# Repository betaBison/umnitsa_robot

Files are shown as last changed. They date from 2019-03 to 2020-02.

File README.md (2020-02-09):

# umnitsa_robot
Umnitsa comes from the englsih transliteration of the russian word "умница" clever pesron or smarty-pants.
Umnitsa is designed to be a clever robot.  
  
See also [umnitsa_msgs](https://github.com/betaBison/umnitsa_msgs), [umnitsa_gs](https://github.com/betaBison/umnitsa_gs), amd [umnitsa_mechanical](https://github.com/betaBison/umnitsa_mechanical).
  
umnitsa_robot is a [metapackage](http://wiki.ros.org/catkin/package.xml#Metapackages) for all the packages that run on the robot's computer. Packages are located in the `src/` directory and a brief description of each is included below.

## Setup
This package is currently compatible with the Raspberry Pi 3 B+ and Jetson Nano.
   
### Raspberry Pi
Install needed dependencies:  
`pip install`

### Jetson Nano
Install needed dependencies:  
`pip2 install Jetson.GPIO pygame nanpy`

Since this repo contains the realsesnse-ros repository as a submodule it's important to run the following command  
`git clone --recursive <URL to git repo>`  
If you failed to do this initially, then inside this repository run  
`git submodule update --init --recursive`  
The realsense-ros also requires the latest [Intel RealSense SDK](https://github.com/IntelRealSense/librealsense/releases). Jetson Nano [installation instructions](https://github.com/JetsonHacksNano/installLibrealsense).

#### Arduino Firmware
Follow directions here to upload correct firmware to arduino (https://github.com/nanpy/nanpy-firmware)

#### Pygame errors:
If there are erros installing pygame, you may need to add its dependencies.  
`sudo apt install libsdl1.2-dev python-dev libsdl-image1.2-dev libsdl-mixer1.2-dev libsdl-ttf2.0-dev libsdl1.2-dev libsmpeg-dev python-numpy subversion libportmidi-dev ffmpeg libswscale-dev libavformat-dev libavcodec-dev`

### Desktop
Since this repo contains the realsesnse-ros repository as a submodule it's important to run the following command  
`git clone --recursive <URL to git repo>`  
If you failed to do this initially, then inside this repository run  
`git submodule update --init --recursive`  
The realsense-ros also requires the latest [Intel RealSense SDK](https://github.com/IntelRealSense/librealsense/releases). Linux [installation instructions](https://github.com/IntelRealSense/librealsense/blob/master/doc/distribution_linux.md). You must install the dev package  
`sudo apt install librealsense2-dkms librealsense2-utils librealsense2-dev`   
   
Install pygame for the joystick controller  
`pip2 install pygame`

## Package Overview
### umnitsa_robot
Empty package that declares packages inside the [metapackage](http://wiki.ros.org/catkin/package.xml#Metapackages).

### umnitsa_robot_launch
This package contains parameters adn launch files for the umnitsa robot. Parameters should be adjusted for compatibility with system setup.

### umnitsa_hardware
This package consists of the harware interfacing nodes as follows:
#### motors
outputs to the motor control board to control four DC motors  

Normal mode:  
The max throttle going forward is 71% on all motors, not 100%. This is so that moving the joystick in a steady
circle produces a steady cirlce of robot movement.  

Turbo mode:  
If the joystick is moved at all, one of the motors is set to 100% throttle. This makes it faster, but unfit for precise movement.

#### RGB
Outputs to the UmnitsaRGB custom PCB  

#### ultrasonic
Inputs from the UmnitsaUltra custom PCB

### umnitsa_joystick
Package that contains the node that that receives input from a switch pro controller and outputs to the joystick message.

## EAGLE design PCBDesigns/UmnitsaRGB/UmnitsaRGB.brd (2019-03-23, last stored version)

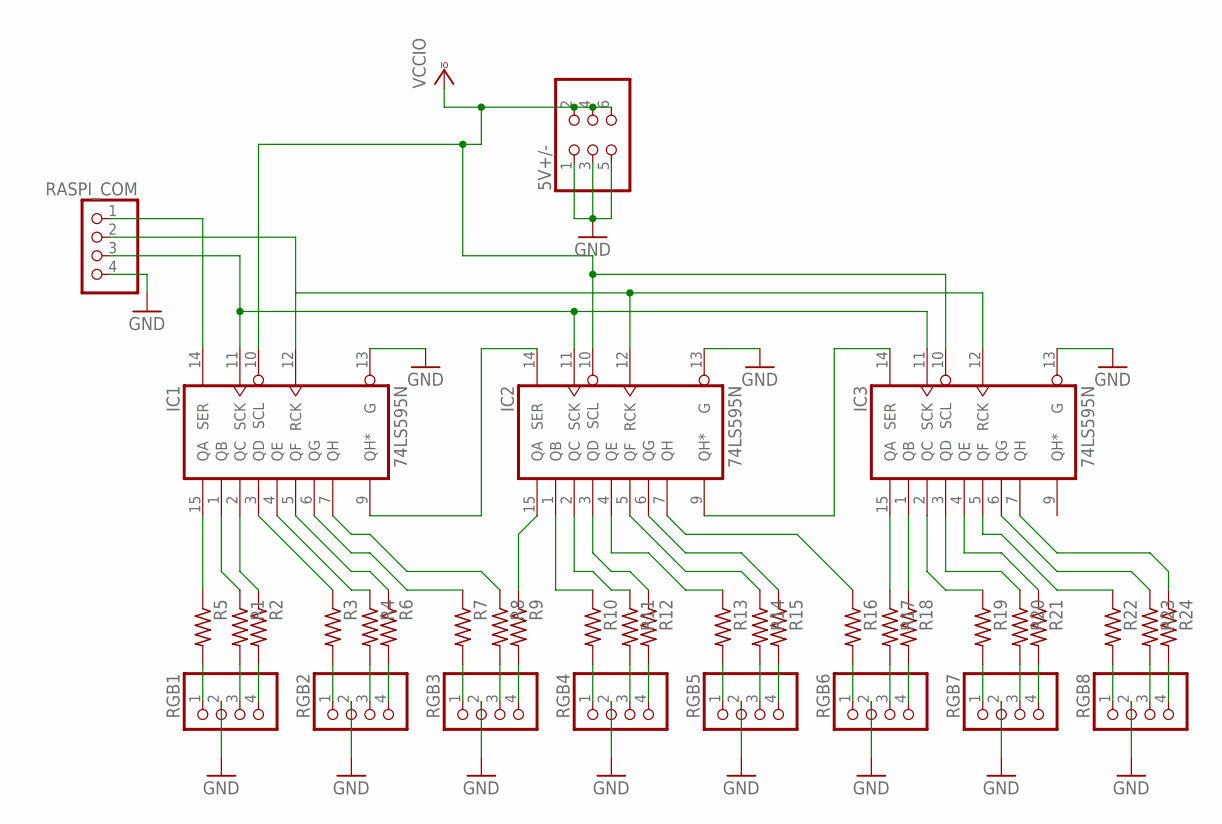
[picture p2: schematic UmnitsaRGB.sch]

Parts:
5V+/-: PINHD-2X3; 2X03
IC1, IC2, IC3: 74LS595N; DIL16
R1, R2, R3, R4, R5, R6, R7, R8, R9, R10, R11, R12, R13, R14, R15, R16, R17, R18, R19, R20, R21, R22, R23, R24: R-US_0204/7; 0204/7
RASPI_COM: PINHD-1X4; 1X04
RGB1, RGB2, RGB3, RGB4, RGB5, RGB6, RGB7, RGB8: PINHD-1X4; 1X04

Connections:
GND: 5V+/-.1, 5V+/-.3, 5V+/-.5, IC1.8 (GND), IC1.13 (G), IC2.8 (GND), IC2.13 (G), IC3.8 (GND), IC3.13 (G), RASPI_COM.4, RGB1.2, RGB2.2, RGB3.2, RGB4.2, RGB5.2, RGB6.2, RGB7.2, RGB8.2
unnamed: R5.2, RGB1.1
unnamed: R1.2, RGB1.3
unnamed: R2.2, RGB1.4
unnamed: R3.2, RGB2.1
unnamed: R4.2, RGB2.3
unnamed: R6.2, RGB2.4
unnamed: R7.2, RGB3.1
unnamed: R8.2, RGB3.3
unnamed: R9.2, RGB3.4
unnamed: R10.2, RGB4.1
unnamed: R11.2, RGB4.3
unnamed: R12.2, RGB4.4
unnamed: R13.2, RGB5.1
unnamed: R14.2, RGB5.3
unnamed: R15.2, RGB5.4
unnamed: R16.2, RGB6.1
unnamed: R17.2, RGB6.3
unnamed: R18.2, RGB6.4
unnamed: IC1.14 (SER), RASPI_COM.1
unnamed: IC1.12 (RCK), IC2.12 (RCK), IC3.12 (RCK), RASPI_COM.2
unnamed: IC1.9 (QH*), IC2.14 (SER)
unnamed: IC2.9 (QH*), IC3.14 (SER)
unnamed: IC1.11 (SCK), IC2.11 (SCK), IC3.11 (SCK), RASPI_COM.3
unnamed: IC1.15 (QA), R5.1
unnamed: IC1.1 (QB), R1.1
unnamed: IC1.2 (QC), R2.1
unnamed: IC1.3 (QD), R3.1
unnamed: IC1.4 (QE), R4.1
unnamed: IC1.5 (QF), R6.1
unnamed: IC1.6 (QG), R7.1
unnamed: IC2.1 (QB), R10.1
unnamed: IC2.15 (QA), R9.1
unnamed: IC1.7 (QH), R8.1
unnamed: IC2.2 (QC), R11.1
unnamed: IC2.3 (QD), R12.1
unnamed: IC2.4 (QE), R13.1
unnamed: IC2.5 (QF), R14.1
unnamed: IC2.6 (QG), R15.1
unnamed: IC2.7 (QH), R16.1
unnamed: IC3.15 (QA), R17.1
unnamed: IC3.1 (QB), R18.1
unnamed: IC3.2 (QC), R19.1
unnamed: IC3.3 (QD), R20.1
unnamed: IC3.4 (QE), R21.1
unnamed: IC3.5 (QF), R22.1
unnamed: IC3.6 (QG), R23.1
unnamed: IC3.7 (QH), R24.1
unnamed: R19.2, RGB7.1
unnamed: R20.2, RGB7.3
unnamed: R21.2, RGB7.4
unnamed: R22.2, RGB8.1
unnamed: R23.2, RGB8.3
unnamed: R24.2, RGB8.4
VCC: IC1.16 (VCC), IC2.16 (VCC), IC3.16 (VCC)
VCCIO: 5V+/-.2, 5V+/-.4, 5V+/-.6, IC1.10 (SCL), IC2.10 (SCL), IC3.10 (SCL)

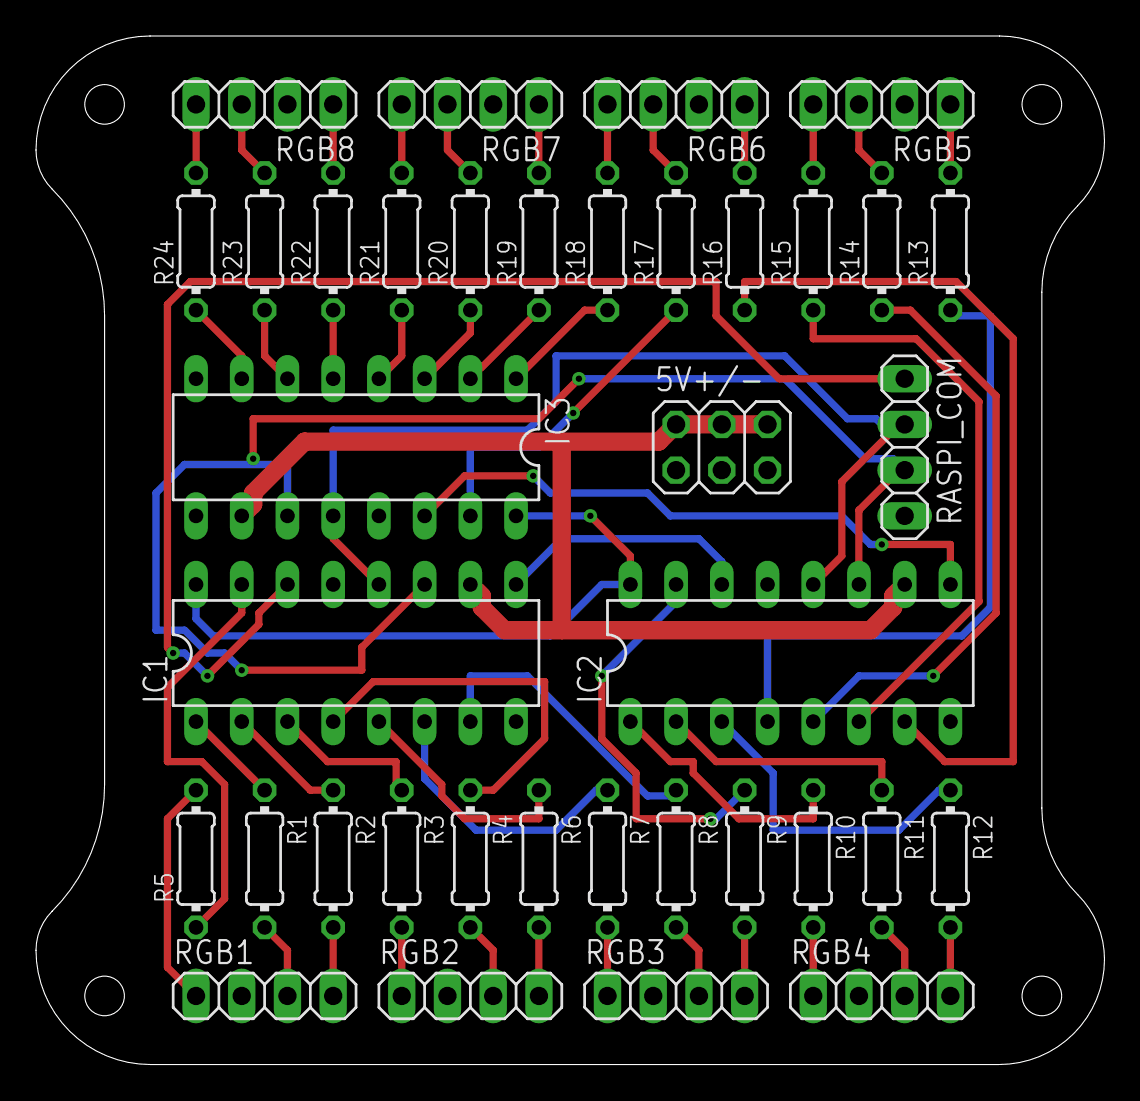
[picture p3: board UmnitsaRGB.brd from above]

Board: 2 copper layers, 59.4 x 57.1 mm, 37 parts (0 on the bottom side), 56 nets.

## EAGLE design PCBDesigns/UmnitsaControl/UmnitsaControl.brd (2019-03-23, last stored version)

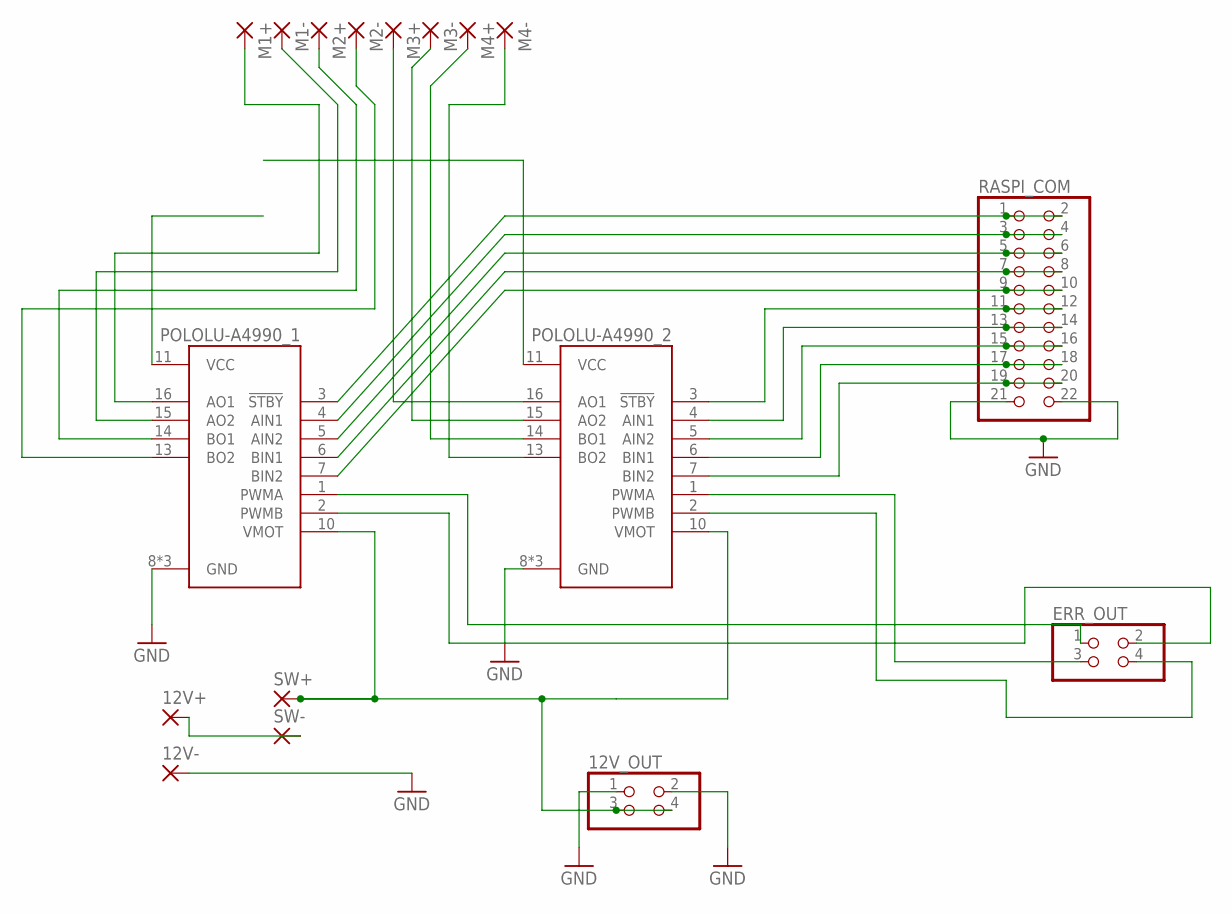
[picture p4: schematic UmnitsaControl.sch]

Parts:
12V+, 12V-: 3,81/1,4
12V_OUT: PINHD-2X2; 2X02
ERR_OUT: PINHD-2X2; 2X02
M1+, M1-, M2+, M2-, M3+, M3-, M4+, M4-: 3,81/1,4
POLOLU-A4990_1, POLOLU-A4990_2: POLOLU-713; SHIELD_POLOLU-713
RASPI_COM: PINHD-2X11; 2X11
SW+: 2,54/1,0
SW-: 2,54/1,0

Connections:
GND: 12V-.1, 12V_OUT.1, 12V_OUT.2, POLOLU-A4990_1.8 (GND), POLOLU-A4990_1.9 (GND), POLOLU-A4990_1.12 (GND), POLOLU-A4990_2.8 (GND), POLOLU-A4990_2.9 (GND), POLOLU-A4990_2.12 (GND), RASPI_COM.21, RASPI_COM.22
unnamed: M1+.1, POLOLU-A4990_1.16 (AO1)
unnamed: M1-.1, POLOLU-A4990_1.15 (AO2)
unnamed: 12V+.1, SW-.1
unnamed: M2+.1, POLOLU-A4990_1.14 (BO1)
unnamed: M2-.1, POLOLU-A4990_1.13 (BO2)
unnamed: M3+.1, POLOLU-A4990_2.16 (AO1)
unnamed: M3-.1, POLOLU-A4990_2.15 (AO2)
unnamed: M4+.1, POLOLU-A4990_2.14 (BO1)
unnamed: M4-.1, POLOLU-A4990_2.13 (BO2)
unnamed: POLOLU-A4990_2.3 (!STBY), RASPI_COM.11, RASPI_COM.12
unnamed: POLOLU-A4990_2.7 (BIN2), RASPI_COM.19, RASPI_COM.20
unnamed: POLOLU-A4990_2.6 (BIN1), RASPI_COM.17, RASPI_COM.18
unnamed: POLOLU-A4990_2.5 (AIN2), RASPI_COM.15, RASPI_COM.16
unnamed: POLOLU-A4990_2.4 (AIN1), RASPI_COM.13, RASPI_COM.14
unnamed: POLOLU-A4990_1.3 (!STBY), RASPI_COM.1, RASPI_COM.2
unnamed: POLOLU-A4990_1.4 (AIN1), RASPI_COM.3, RASPI_COM.4
unnamed: POLOLU-A4990_1.5 (AIN2), RASPI_COM.5, RASPI_COM.6
unnamed: POLOLU-A4990_1.6 (BIN1), RASPI_COM.7, RASPI_COM.8
unnamed: POLOLU-A4990_1.7 (BIN2), RASPI_COM.9, RASPI_COM.10
unnamed: ERR_OUT.3, POLOLU-A4990_2.1 (PWMA)
unnamed: ERR_OUT.4, POLOLU-A4990_2.2 (PWMB)
unnamed: ERR_OUT.1, POLOLU-A4990_1.1 (PWMA)
unnamed: ERR_OUT.2, POLOLU-A4990_1.2 (PWMB)
unnamed: 12V_OUT.3, 12V_OUT.4, POLOLU-A4990_1.10 (VMOT), POLOLU-A4990_2.10 (VMOT), SW+.1

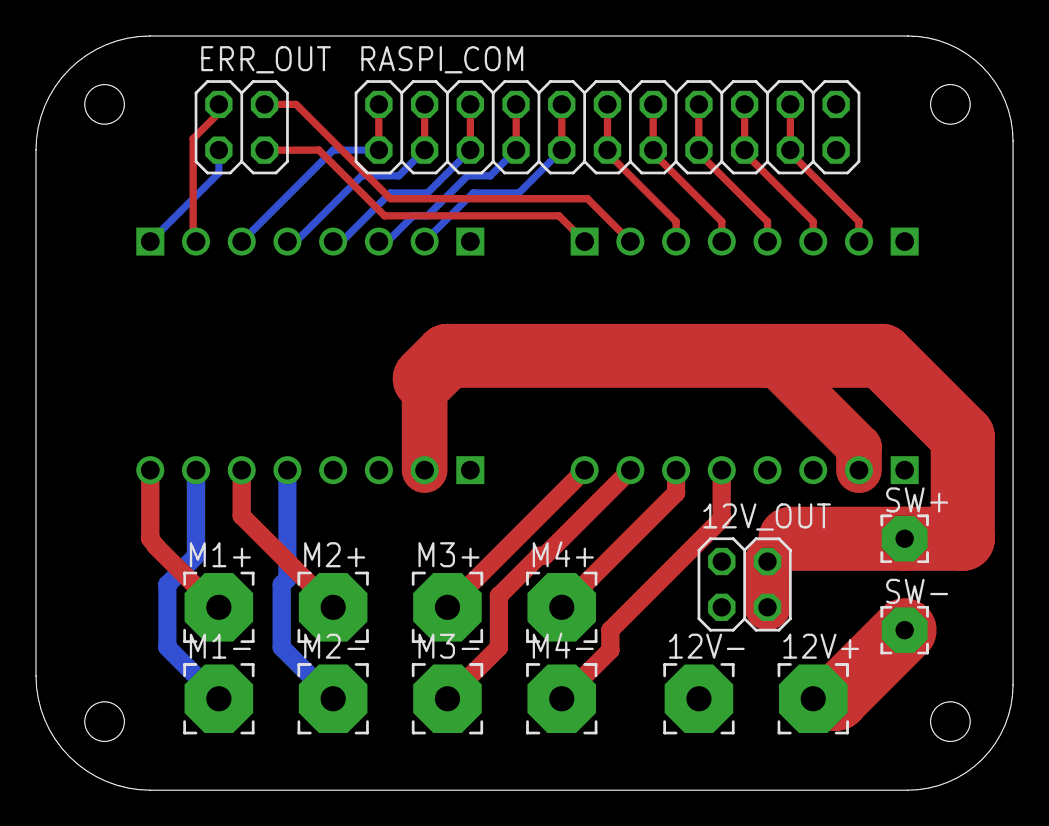
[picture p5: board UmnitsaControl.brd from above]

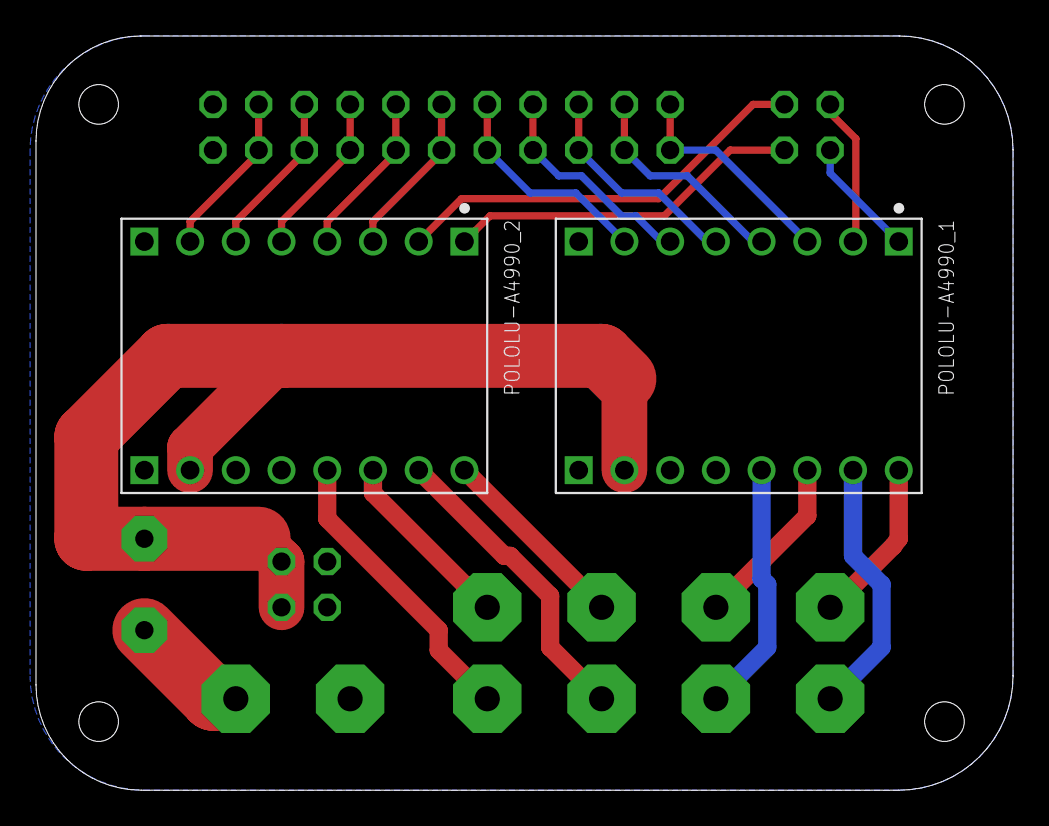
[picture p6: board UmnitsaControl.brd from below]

Board: 2 copper layers, 54.3 x 41.9 mm, 17 parts (2 on the bottom side), 25 nets.

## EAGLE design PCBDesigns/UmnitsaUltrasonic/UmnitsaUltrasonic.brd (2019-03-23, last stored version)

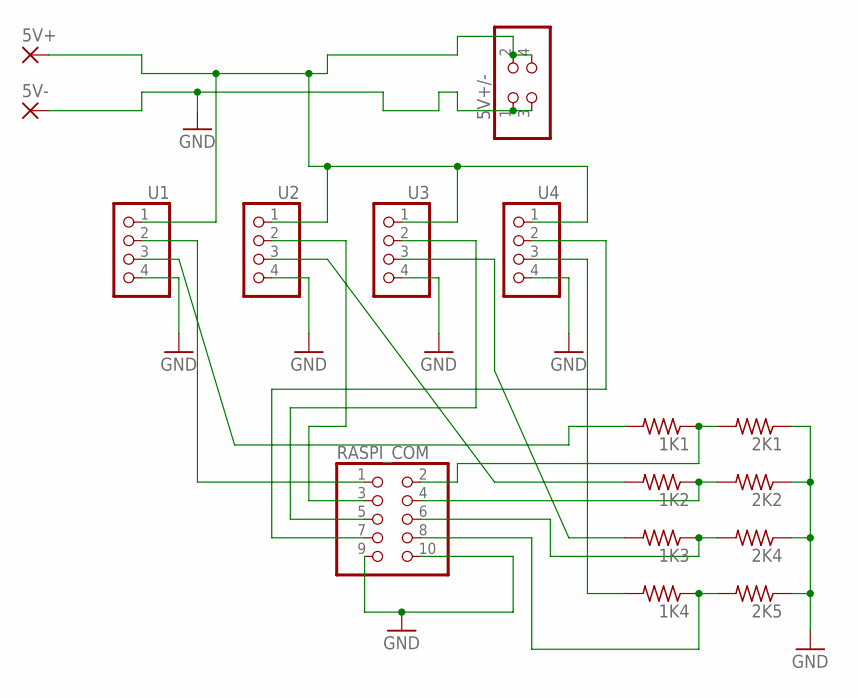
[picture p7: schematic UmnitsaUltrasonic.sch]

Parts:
1K1, 1K2, 1K3, 1K4, 2K1, 2K2, 2K4, 2K5: R-US_0204/7; 0204/7
5V+, 5V-: 3,17/1,3
5V+/-: PINHD-2X2; 2X02
RASPI_COM: PINHD-2X5; 2X05
U1, U2, U3, U4: PINHD-1X4; 1X04

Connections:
GND: 2K1.1, 2K2.1, 2K4.1, 2K5.1, 5V+/-.1, 5V+/-.3, 5V-.1, RASPI_COM.9, RASPI_COM.10, U1.4, U2.4, U3.4, U4.4
unnamed: 1K4.2, U4.3
unnamed: 1K3.2, U3.3
unnamed: 1K1.1, 2K1.2, RASPI_COM.2
unnamed: 1K2.1, 2K2.2, RASPI_COM.4
unnamed: 1K3.1, 2K4.2, RASPI_COM.6
unnamed: 5V+.1, 5V+/-.2, 5V+/-.4, U1.1, U2.1, U3.1, U4.1
unnamed: 1K4.1, 2K5.2, RASPI_COM.8
unnamed: RASPI_COM.1, U1.2
unnamed: RASPI_COM.3, U2.2
unnamed: RASPI_COM.5, U3.2
unnamed: RASPI_COM.7, U4.2
unnamed: 1K2.2, U2.3
unnamed: 1K1.2, U1.3

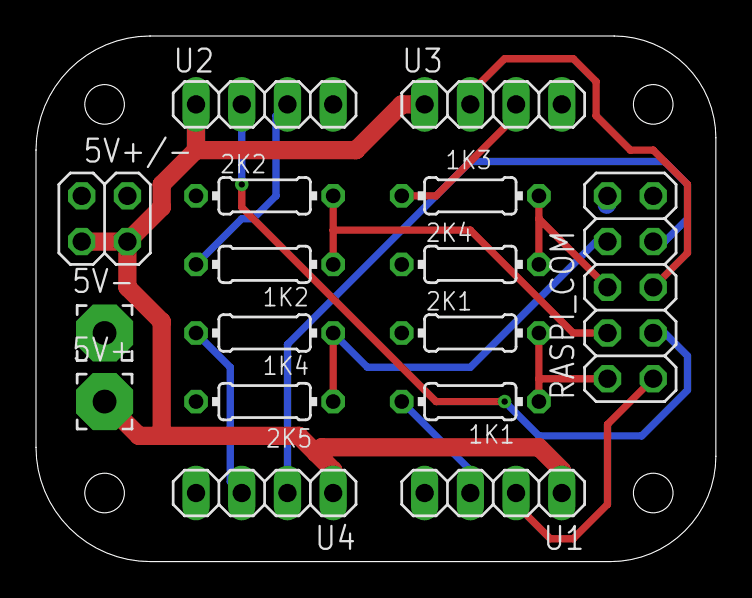
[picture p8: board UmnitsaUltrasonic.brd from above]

Board: 2 copper layers, 37.8 x 29.2 mm, 16 parts (0 on the bottom side), 14 nets.

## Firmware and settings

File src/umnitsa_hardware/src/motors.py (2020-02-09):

#!/usr/bin/env python
"""
Author: D. Knowles
Desc  : ROS node that outputs to the umnitsaControl board
"""
import os
import time
import rospy
from geometry_msgs.msg import Twist
from umnitsa_msgs.msg import Joystick
if (os.environ['ARCHITECTURE'] == 'raspi'):
	import RPi.GPIO as GPIO
elif (os.environ['ARCHITECTURE'] == 'nano'):
	import nanpy
from math import atan2, cos, pi, sqrt
import numpy as np

class Motors():
	def __init__(self):
		"""
		initialize pins as motor outputs
		"""

		self.DB1 = rospy.get_param('DB1') # Driver Board #1 INH
		self.M1 = rospy.get_param('M1')   # DB #1 IN1 & IN2
		self.M2 = rospy.get_param('M2')   # DB #1 IN3 & IN4
		self.DB2 = rospy.get_param('DB2') # DB #2 INH
		self.M3 = rospy.get_param('M3')   # DB #2 IN1 & IN2
		self.M4 = rospy.get_param('M4')   # DB #2 IN3 & IN4

		self.turbo = False		# turbo mode
		self.arch = os.environ['ARCHITECTURE']

		if self.arch == 'raspi':
			GPIO.setmode(GPIO.BOARD)          # use RasPi pin numbers
			GPIO.setwarnings(False)     # don't show setup warnings
			# set pins as outputs and initialize to False/Low
			GPIO.setup(self.DB1,GPIO.OUT,initial=False)
			GPIO.setup(self.M1,GPIO.OUT,initial=False)
			GPIO.setup(self.M2,GPIO.OUT,initial=False)
			GPIO.setup(self.DB2,GPIO.OUT,initial=False)
			GPIO.setup(self.M3,GPIO.OUT,initial=False)
			GPIO.setup(self.M4,GPIO.OUT,initial=False)

			# setup all pwm outputs
			self.frequency = 500.0          # pwm frequency
			self.PWM_M1 = GPIO.PWM(self.M1,self.frequency)
			self.PWM_M1.start(0.0)
			self.PWM_M2 = GPIO.PWM(self.M2,self.frequency)
			self.PWM_M2.start(0.0)
			self.PWM_M3 = GPIO.PWM(self.M3,self.frequency)
			self.PWM_M3.start(0.0)
			self.PWM_M4 = GPIO.PWM(self.M4,self.frequency)
			self.PWM_M4.start(0.0)

		else:
			no_connection = True
			while no_connection:
				try:
					connection = nanpy.SerialManager()
					self.a = nanpy.ArduinoApi(connection = connection)
					no_connection = False
				except:
					print("Failed to connect to Arduino")
			self.a.pinMode(self.DB1, self.a.OUTPUT)
			self.a.pinMode(self.M1, self.a.OUTPUT)
			self.a.pinMode(self.M2, self.a.OUTPUT)
			self.a.pinMode(self.DB2, self.a.OUTPUT)
			self.a.pinMode(self.M3, self.a.OUTPUT)
			self.a.pinMode(self.M4, self.a.OUTPUT)

	def subscribe(self):
		rospy.init_node('motors', anonymous=False)
		rospy.Subscriber('cmd_vel',Twist, self.updateOutput)
		rospy.Subscriber('commands',Joystick, self.updateSettings)
		# spin() simply keeps python from exiting until this node is stopped
		rospy.spin()

	def updateSettings(self,commands):
		if commands.TYPE == "BUTTON":
			if commands.X:
				self.turbo = not(self.turbo)

	def updateOutput(self,cmd_vel):
		# check if any toggle is not 0.0 (i.e. False)
		if cmd_vel.linear.x or cmd_vel.linear.y or cmd_vel.angular.z:
			lateral = self.lateral(cmd_vel.linear.x,cmd_vel.linear.y)
			rotation = self.rotation(cmd_vel.angular.z)
			motor_output = lateral + rotation
			if np.amax(abs(motor_output)) > 1.0:
				# scale result by highest output
				motor_output /= np.amax(abs(motor_output))
			elif self.turbo:
				# turbo mode amplifies all signals relative to highest
				motor_output /= np.amax(abs(motor_output))
			x_M1 = motor_output.item(0)
			x_M2 = motor_output.item(1)
			x_M3 = motor_output.item(2)
			x_M4 = motor_output.item(3)

			print("motor outputs: ",x_M1,x_M2,x_M3,x_M4)

			if self.arch == 'raspi':
				self.PWM_M1.ChangeDutyCycle(50.0 + x_M1*50.0)
				self.PWM_M2.ChangeDutyCycle(50.0 + x_M2*50.0)
				self.PWM_M3.ChangeDutyCycle(50.0 + x_M3*50.0)
				self.PWM_M4.ChangeDutyCycle(50.0 + x_M4*50.0)

				GPIO.output(self.DB1,True)   # enable DB #1
				GPIO.output(self.DB2,True)   # enable DB #2
			else:
				self.a.analogWrite(self.M1,255*(0.5 + x_M1*0.5))
				self.a.analogWrite(self.M2,255*(0.5 + x_M2*0.5))
				self.a.analogWrite(self.M3,255*(0.5 + x_M3*0.5))
				self.a.analogWrite(self.M4,255*(0.5 + x_M4*0.5))

				self.a.digitalWrite(self.DB1,self.a.HIGH) # enable DB #1
				self.a.digitalWrite(self.DB2,self.a.HIGH) # enable DB #2

		else:
			# disable output if right and left toggle are 0.0
			if self.arch == 'raspi':
				GPIO.output(self.DB1,False)
				GPIO.output(self.DB2,False)
			else:
				self.a.digitalWrite(self.DB1,self.a.LOW)
				self.a.digitalWrite(self.DB2,self.a.LOW)


	def rotation(self,LTOGRIGHT):
		"""
		rotate robot with the left toggle
		"""
		x = -LTOGRIGHT

		return np.array([x,x,x,x])


	def lateral(self,vel_x,vel_y):
		"""
		move robot laterally with the right toggle
		"""
		if abs(vel_x) > 0.0 or abs(vel_y) > 0.0:

			direction = atan2(vel_x,-vel_y) # direction of toggle movement
			mag = sqrt(vel_x**2+vel_y**2) # magnitude of toggle movement
			print("magnitude=",mag)

			# compute each motor throttle to move in toggle direction
			x_M1 = mag*cos(direction+pi/4.)
			x_M2 = -mag*cos(direction+pi/4.)
			x_M3 = mag*cos(direction-pi/4.)
			x_M4 = -mag*cos(direction-pi/4.)

			return np.array([x_M1,x_M2,x_M3,x_M4])
		else:
			return np.array([0.0, 0.0, 0.0, 0.0])

	def cw(self,x):
		"""
		moves robot clockwise
		input: x = throttle (0.0,1.0)
		"""
		self.PWM_M1.ChangeDutyCycle(50.0 + x*50.0)
		self.PWM_M2.ChangeDutyCycle(50.0 + x*50.0)
		self.PWM_M3.ChangeDutyCycle(50.0 + x*50.0)
		self.PWM_M4.ChangeDutyCycle(50.0 + x*50.0)

		GPIO.output(self.DB1,True)   # enable DB #1
		GPIO.output(self.DB2,True)   # enable DB #2

	def ccw(self,x):
		"""
		moves robot counter clockwise
		input: x = throttle (0.0,1.0)
		"""
		self.PWM_M1.ChangeDutyCycle(50.0 - x*50.0)
		self.PWM_M2.ChangeDutyCycle(50.0 - x*50.0)
		self.PWM_M3.ChangeDutyCycle(50.0 - x*50.0)
		self.PWM_M4.ChangeDutyCycle(50.0 - x*50.0)

		GPIO.output(self.DB1,True)   # enable DB #1
		GPIO.output(self.DB2,True)   # enable DB #2

	def forward(self,x):
		"""
		moves robot backwards
		input: x = throttle (0.0,1.0)
		"""
		self.PWM_M1.ChangeDutyCycle(50.0 - x*50.0)
		self.PWM_M2.ChangeDutyCycle(50.0 + x*50.0)
		self.PWM_M3.ChangeDutyCycle(50.0 + x*50.0)
		self.PWM_M4.ChangeDutyCycle(50.0 - x*50.0)

		GPIO.output(self.DB1,True)   # enable DB #1
		GPIO.output(self.DB2,True)   # enable DB #2

	def backward(self,x):
		"""
		moves robot forward
		input: x = throttle (0.0,1.0)
		"""
		self.PWM_M1.ChangeDutyCycle(50.0 + x*50.0)
		self.PWM_M2.ChangeDutyCycle(50.0 - x*50.0)
		self.PWM_M3.ChangeDutyCycle(50.0 - x*50.0)
		self.PWM_M4.ChangeDutyCycle(50.0 + x*50.0)

		GPIO.output(self.DB1,True)   # enable DB #1
		GPIO.output(self.DB2,True)   # enable DB #2


	def right(self,x):
		"""
		moves robot right
		input: x = throttle (0.0,1.0)
		"""
		self.PWM_M1.ChangeDutyCycle(50.0 + x*50.0)
		self.PWM_M2.ChangeDutyCycle(50.0 - x*50.0)
		self.PWM_M3.ChangeDutyCycle(50.0 + x*50.0)
		self.PWM_M4.ChangeDutyCycle(50.0 - x*50.0)

		GPIO.output(self.DB1,True)   # enable DB #1
		GPIO.output(self.DB2,True)   # enable DB #2


	def left(self,x):
		"""
		moves robot left
		input: x = throttle (0.0,1.0)
		"""
		self.PWM_M1.ChangeDutyCycle(50.0 - x*50.0)
		self.PWM_M2.ChangeDutyCycle(50.0 + x*50.0)
		self.PWM_M3.ChangeDutyCycle(50.0 - x*50.0)
		self.PWM_M4.ChangeDutyCycle(50.0 + x*50.0)

		GPIO.output(self.DB1,True)   # enable DB #1
		GPIO.output(self.DB2,True)   # enable DB #2

	def disable(self):
		"""
		disable both motor driver boards
		"""
		if self.arch == 'raspi':
			GPIO.output(self.DB1,False)
			GPIO.output(self.DB2,False)
		else:
			self.a.digitalWrite(self.DB1,self.a.LOW)
			self.a.digitalWrite(self.DB2,self.a.LOW)

if __name__ == '__main__':
	try:
		subscriber = Motors()
		subscriber.subscribe()
	except rospy.ROSInterruptException:
		subscriber.disable()

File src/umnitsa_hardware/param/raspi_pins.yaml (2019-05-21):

# Raspberry Pi pinout configuration parameters

# motor control pins
DB1: 7                     # Driver Board #1 INH
M1: 8                      # DB #1 IN1 & IN2
M2: 10                      # DB #1 IN3 & IN4
DB2: 11                     # DB #2 INH
M3: 12                     # DB #2 IN1 & IN2
M4: 13                     # DB #2 IN3 & IN4

# ultrasonic pins
ULTRA1_TRIG: 18
ULTRA1_ECHO: 19
ULTRA2_TRIG: 21
ULTRA2_ECHO: 22
ULTRA3_TRIG: 23
ULTRA3_ECHO: 24
ULTRA4_TRIG: 26
ULTRA4_ECHO: 29

# rgb pins
BUZ: 36
RGB_SDI: 37
RGB_RCLK: 38
RGB_SRCLK: 40

# Magnetometer
SDA: 3
SCL: 5

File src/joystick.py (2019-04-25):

#!/usr/bin/env python
"""
Author: D. Knowles
Desc  : ROS node that publishes the joystick information
"""

import time
import sys
sys.path.append("..")
import os
import pygame
import rospy
from umnitsa_msgs.msg import joystick
import param_joystick as J
import numpy as np
from subprocess import call

class JoystickPublisher():
    def __init__(self):
        # initialize axes from parameter file
        self.LTOGRIGHT = J.LTOGRIGHT
        self.LTOGUP = J.LTOGUP
        self.RTOGRIGHT = J.RTOGRIGHT
        self.RTOGUP = J.RTOGUP
        self.calibration = [1.0,    # LTOG Right
                            1.0,    # LTOG Left
                            1.0,    # LTOG Up
                            1.0,    # LTOG Down
                            1.0,    # RTOG Right
                            1.0,    # RTOG Left
                            1.0,    # RTOG Up
                            1.0]    # RTOG Down


        # initilize buttons and hat from parameter file
        # initilize buttons from parameter file
        self.B = J.B
        self.A = J.A
        self.Y = J.Y
        self.X = J.X
        self.L = J.L
        self.R = J.R
        self.ZL = J.ZL
        self.ZR = J.ZR
        self.MINUS = J.MINUS
        self.PLUS = J.PLUS
        self.LCLICK = J.LCLICK
        self.RCLICK = J.RCLICK
        self.HOME = J.HOME
        self.CAPTURE = J.CAPTURE
        # initialize hat from parameter file
        self.UP = J.UP
        self.DOWN = J.DOWN
        self.RIGHT = J.RIGHT
        self.LEFT = J.LEFT

        self.button_pins = [J.B,
                            J.A,
                            J.Y,
                            J.X,
                            J.L,
                            J.R,
                            J.ZL,
                            J.ZR,
                            J.MINUS,
                            J.PLUS,
                            J.LCLICK,
                            J.RCLICK,
                            J.HOME,
                            J.CAPTURE]

        self.num_buttons = len(self.button_pins)
        self.button_status = np.zeros((self.num_buttons,1))

        self.hat_status = np.zeros((4,1))

        self.command_publisher = rospy.Publisher('commands', joystick, queue_size=10)
        rospy.init_node('talker', anonymous=True)
        self.commands = joystick()

        sys.stdout = sys.stderr# ignore pygame messages
        os.environ["SDL_VIDEODRIVER"] = "dummy" # Removes the need to have a GUI window
        pygame.init()
        self.initialized = False
        self.found = False
        self.axis_timer = time.time()
        self.timeout = 0.1
        self.axis_updated = False

    def publish(self):
        while not rospy.is_shutdown():
            if not(self.initialized):
                try:
                    pygame.joystick.init()
                    # Attempt to setup the joystick
                    if pygame.joystick.get_count() < 1:
                        # No joystick attached, set LEDs blue
                        pygame.joystick.quit()
                        time.sleep(0.1)
                    else:
                        # We have a joystick, attempt to initialise it!
                        self.joystick = pygame.joystick.Joystick(0)
                        self.found = True
                except pygame.error:
                    # Failed to connect to the joystick, set LEDs blue
                    pygame.joystick.quit()
                    time.sleep(0.1)
                if self.found:
                    print('Joystick found')
                    self.joystick.init()
                    self.initialized = True
            else:
                events = pygame.event.get()
                # handle events separately
                if len(events) > 0:
                    for event in events:
                        if event.type == pygame.JOYAXISMOTION:
                            self.updateAxis()
                            self.commands.TYPE = "AXIS"
                            self.updateButtonsandHats()


                        elif event.type == pygame.JOYBUTTONDOWN:
                            self.updateButtonsandHats()

                        elif event.type == pygame.JOYBUTTONUP:
                            self.updateButtonsandHats()

                        elif event.type == pygame.JOYHATMOTION:
                            self.updateButtonsandHats()

                        rospy.loginfo(self.commands)

                        # only publish commands if timeout has passed
                        if self.commands.TYPE != "AXIS" or (self.commands.TYPE == "AXIS" and (time.time() - self.axis_timer) > self.timeout):
                            self.command_publisher.publish(self.commands) # publish updated commands
                            if self.commands.TYPE == "AXIS":
                                self.axis_timer = time.time()
                                self.axis_updated = True

                # runs if there aren't any events
                else:
                    # check if any axis is nonzero
                    if (time.time() - self.axis_timer) > self.timeout and self.axis_updated:
                        self.updateAxis()
                        self.commands.TYPE = "AXIS"
                        self.command_publisher.publish(self.commands) # publish updated commands
                        self.axis_updated = False



    def updateAxis(self):
        LTOGRIGHT = self.joystick.get_axis(self.LTOGRIGHT)
        if LTOGRIGHT > 0:
            self.commands.LTOGRIGHT = self.saturate(self.calibration[0]*LTOGRIGHT)
        else:
            self.commands.LTOGRIGHT = self.saturate(self.calibration[1]*LTOGRIGHT)

        LTOGUP = self.joystick.get_axis(self.LTOGUP)
        if LTOGUP > 0:
            self.commands.LTOGUP = self.saturate(-self.calibration[2]*LTOGUP)
        else:
            self.commands.LTOGUP = self.saturate(-self.calibration[3]*LTOGUP)

        RTOGRIGHT = self.joystick.get_axis(self.RTOGRIGHT)
        if RTOGRIGHT > 0:
            self.commands.RTOGRIGHT = self.saturate(self.calibration[4]*RTOGRIGHT)
        else:
            self.commands.RTOGRIGHT = self.saturate(self.calibration[5]*RTOGRIGHT)

        RTOGUP = self.joystick.get_axis(self.RTOGUP)
        if RTOGUP > 0:
            self.commands.RTOGUP = self.saturate(-self.calibration[6]*RTOGUP)
        else:
            self.commands.RTOGUP = self.saturate(-self.calibration[7]*RTOGUP)

    def checkButtons(self):
        new_status = np.zeros((self.num_buttons,1))
        for ii in range(self.num_buttons):
            if self.joystick.get_button(self.button_pins[ii]):
                new_status[ii] = True
        XOR = abs(self.button_status - new_status)
        index_change = np.where(XOR)[0]
        self.button_status = new_status
        return index_change
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

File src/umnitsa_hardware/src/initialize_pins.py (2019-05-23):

"""
Author: D. Knowles
Desc  : initialize all pins low at startup
"""

import sys
sys.path.append('..')
import os
if (os.environ['ARCHITECTURE'] == 'raspi'):
    import RPi.GPIO as GPIO
    import param.raspi_pins as P
elif (os.environ['ARCHITECTURE'] == 'nano'):
    import Jetson.GPIO as GPIO
    import param.nano_pins as P

GPIO.setmode(GPIO.BOARD)    # use RasPi pin numbers

GPIO.setwarnings(False)     # don't show setup warnings
# set pins as outputs and initialize to False/Low
# motor control
GPIO.setup(P.DB1,GPIO.OUT,initial=False)
GPIO.setup(P.M1,GPIO.OUT,initial=False)
GPIO.setup(P.M2,GPIO.OUT,initial=False)
GPIO.setup(P.DB2,GPIO.OUT,initial=False)
GPIO.setup(P.M3,GPIO.OUT,initial=False)
GPIO.setup(P.M4,GPIO.OUT,initial=False)
#rgb pins
GPIO.setup(P.RGB_SDI,GPIO.OUT,initial=False)
GPIO.setup(P.RGB_RCLK,GPIO.OUT,initial=False)
GPIO.setup(P.RGB_SRCLK,GPIO.OUT,initial=False)

print("initialized")

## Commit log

2016-02-11 tab error, working now on rpi
    [joystick.py]
2016-02-11 24 leds for template
2019-03-12 single motor testing
2019-03-12 basic pwm movement test
2019-03-13 motor pins global
2019-03-18 software pwm and ultrasonic test
2019-03-18 change print statement
2019-03-18 ros framework
2019-03-21 print error
2019-03-23 PCB Design files
    [UmnitsaControl.brd, UmnitsaControl.sch, UmnitsaRGB.brd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]
2019-03-23 PCB documentation
    [UmnitsaControl.brd, UmnitsaControl.sch, UmnitsaRGB.brd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]
2019-03-23 current rating for UmnitsaControl
2019-03-24 switch pro controller test
2019-03-24 4 button test
2019-03-24 reverse order bit control
    [rgb.py]
2019-03-24 2 Hz joystick
2019-03-24 only publish axis at 2Hz
2019-03-27 added all joystick buttons
2019-03-29 button priority msg, global pin names
2019-03-30 pin change
2019-03-30 ultrasonic publisher
2019-03-30 start of motor subscriber
2019-03-30 added ultrasonic message
2019-03-31 joystick calibration
2019-04-06 prevent over waiting with default value
    [ultraTest.py]
2019-04-18 pin changes
2019-04-18 error check on joystick init
    [joystick.py]
2019-04-18 only sent axis at 10Hz
2019-04-18 update timer
2019-04-19 joystick and motor launch
2019-04-19 discretize LEDs
2019-04-19 start rgb and ultrasonic
2019-04-19 correct magnitude right toggle
    [motors.py]
2019-04-19 ros raspberry readme
2019-05-09 move subdirectories into new repositories
    [UmnitsaControl.brd, UmnitsaControl.sch, UmnitsaRGB.brd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]
2019-05-22 conforming motors
2020-02-09 nano arduino implementation
